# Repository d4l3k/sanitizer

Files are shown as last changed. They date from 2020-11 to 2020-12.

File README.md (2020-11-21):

# sanitizer

Building a box lined with aluminum foil and mounting this in the top of the box
is probably the best way to disinfect things quickly.

## UVC Leds Power by distance away

For a half sphere falloff:

 * $36 mW  /(4 pi * (32 cm)^2/2) * 15*60 seconds = 5 mJ/cm^2$
 * $36 mW  /(4 pi * (100 cm)^2/2) * 2.5*60*60 seconds = 5.157mJ/cm^2$
 * $36 mW  /(4 pi * (200 cm)^2/2) * 10*60*60 seconds = 5.157mJ/cm^2$

## Power to kill SARS-CoV-2

 | power |1.25 mJ/cm^2 |2.5 mJ/cm^2 |3.75 mJ/cm^2 | 5 mJ/cm2 |
 |---|----|---|---|---|
 | time at 1.25 mW/cm^2 |1 second | 2 seconds | 3 seconds | 4 seconds |
 |  260 nm |   |   |   | 2.6 |
 |  268 nm |0.7 | 1.2 | 1.5 | 2.8|
 |  270 nm |   |   |   | 2.8 |

 from https://www.klaran.com/crystal-is-and-boston-university-research-demonstrate-klaran-uvc-leds-effective-wavelength-for-inactivating-sars-cov-2

## Aluminum foil reflectivity

Aluminum foil has a reflectivity of 73% for UVC light.

https://www.klaran.com/images/kb/application-notes/Using-UV-Reflective-Materials-to-Maximize-Disinfection---Application-Note---AN011.pdf

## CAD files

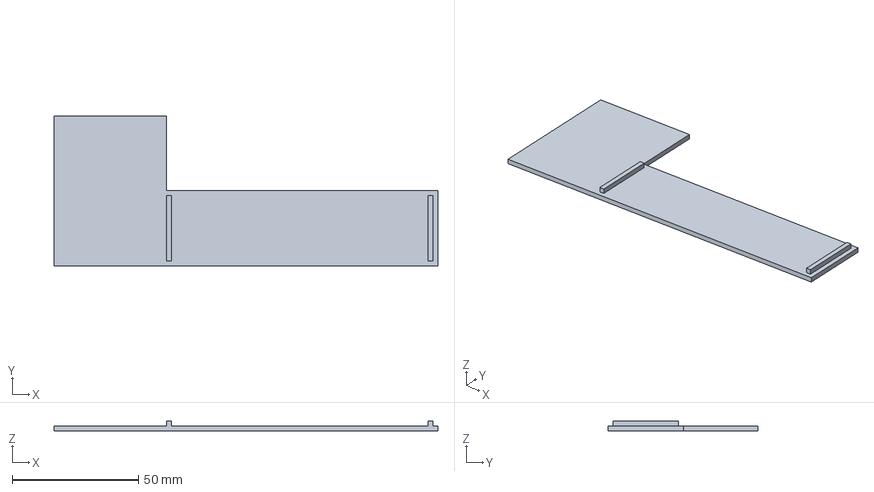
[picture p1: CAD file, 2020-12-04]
sanitizer-case-top.amf
152.2 x 59.6 x 4.00 mm

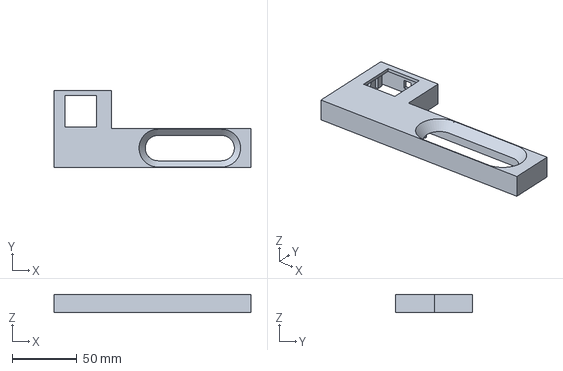
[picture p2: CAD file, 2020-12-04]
sanitizer-case.amf
152.2 x 59.6 x 14.0 mm

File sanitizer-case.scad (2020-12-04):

$fn = 50;

board_width = 25;
  board_length = 110;
  board_hole_size = 1.5;
  board_max_height = 6.15;
  board_min_height = 1.44;
 
board_hole1_offset = 79.5;
board_hole2_offset = 5.5;
  
module led_board() {
  
  led_size = 3.58;
  
  translate([0, -board_width/2])
  difference() {
    union() {
    cube([board_length, board_width, board_min_height]);
    cube([board_width, board_width, board_max_height]);
    }
    
      
    translate([board_length-board_hole1_offset-board_hole_size, board_width/2, -1])
    cylinder(r=board_hole_size, h=5);
    
    translate([board_length-board_hole2_offset-board_hole_size, board_width/2, -1])
    cylinder(r=board_hole_size, h=5);

  }
  
  for (d = [76.95, 46.97, 16.62]) {
    translate([board_length-d, -led_size/2, board_min_height])
    cube([led_size, led_size, 1.6]);
  }
}

 strip_width = 10.1;
  strip_length = 33;
  led_size = 5;

module led_strip() {
  translate([0, -strip_width/2])
  union() {
    cube([strip_length, strip_width, 0.26]);
    
    translate([strip_length/2-led_size/2,strip_width/2-led_size/2])
    cube([led_size, led_size, 2]);
  }
}
  thread_outer = 6.8;
  thread_inner = 6.13;
  thread_length = 6.23;
  lip_outer = 9.5;
  lip_length = 2;
  barrel_diameter = 7.37;
  barrel_length = 12.5;
  stem_diameter=4.5;
  stem_length = 2.2;
  button_diameter=6;
  button_length = 3.7;

module button() {
  translate([0, 0, -barrel_length-lip_length]) {
  cylinder(d=barrel_diameter, h=barrel_length);
  translate([0,0,barrel_length])
  cylinder(d=lip_outer, h=lip_length);
  translate([0,0,barrel_length+lip_length])
  cylinder(d=thread_outer, h=thread_length);
  translate([0,0,barrel_length+lip_length+thread_length])
  cylinder(d=stem_diameter, h=stem_length);
    translate([0,0,barrel_length+lip_length+thread_length+stem_length])
  cylinder(d=button_diameter, h=button_length);
  }

}

  sensor_length = 32.57;
  sensor_width = 24.26;
  sensor_height = 11;
  cap_size = 23.25;
  cap_base = 3.4;
  
module motion_sensor() {

  translate([0, -sensor_width/2])
    
  union() {
    cube([sensor_length, sensor_width, sensor_height]);
    
    translate([sensor_length/2-cap_size/2, sensor_width/2-cap_size/2, sensor_height])
    union() {
    cube([cap_size, cap_size, cap_base]);
      translate([cap_size/2, cap_size/2, cap_base])
      sphere(cap_size/2);
    }
  }
}
chip_hole_radius = 2.9/2;

module chip_hole() {
  cylinder(r=chip_hole_radius, h=5);
}

chip_width = 25.63;
chip_length = 48.42;
chip_height = 1.63;
port_width = 11.5;
port_height = 6.78;
port_length = 24.40;

pin_width = 2.57;
pin_length = 36.16;
pin_height = 8.31;

chip_hole_offset_x = 0.8;
chip_hole_offset_y = 1.06;


module chip() {
  
  translate([0, -chip_width/2])
  union() {
  
  translate([0, chip_width/2+(port_width-port_height)/2, 6.14-port_height])
  rotate([90, 0, 270])
  union() {
    cube([port_width-port_height, port_height, port_length]);
    translate([0, port_height/2])
    union() {
      cylinder(d=port_height, h=port_length);

      translate([port_width-port_height, 0])
      cylinder(d=port_height, h=port_length);
    }
  }
  
  difference() {
    cube([chip_length, chip_width, chip_height]);
    
    translate([chip_hole_radius+chip_hole_offset_x, chip_hole_radius+chip_hole_offset_y,-1])
    chip_hole();
    translate([chip_hole_radius+chip_hole_offset_x, chip_width-chip_hole_offset_y-chip_hole_radius,-1])
    chip_hole();
    
    translate([chip_length-chip_hole_radius-chip_hole_offset_x, chip_hole_radius+chip_hole_offset_y,-1])
    chip_hole();
    translate([chip_length-chip_hole_radius-chip_hole_offset_x, chip_width-chip_hole_offset_y-chip_hole_radius,-1])
    chip_hole();
  }

  
  translate([chip_length/2-pin_length/2, 0, -pin_height])
  union() {
    cube([pin_length, pin_width, pin_height]);
    translate([0, chip_width-pin_width])
      cube([pin_length, pin_width, pin_height]);
  }
  }
}
  small_chip_width = 25.8;
  small_chip_length = 34.21;
  small_chip_height = 4.28; // includes boards
  small_board_height = 1.16;




module small_chip() {
  board_width = small_chip_width;
    board_length = small_chip_length;
  board_height = small_board_height;

  cube([board_length, board_width, board_height]);
  
  subboard_width = 16;
  subboard_length = 24.16;
  translate([board_length-subboard_length, (board_width-subboard_width)/2, board_height])
  cube([24.16, 16, 0.8]);
  
  chip_width = 11.88;
  chip_length = 15;
  
  translate([11.55, (board_width-chip_width)/2, 0])
  cube([chip_length, chip_width, small_chip_height]);
  
  translate([0, board_width/2+(port_width-port_height)/2, 0.84-port_height+board_height])
  rotate([90, 0, 270])
  union() {
    cube([port_width-port_height, port_height, port_length]);
    translate([0, port_height/2])
    union() {
      cylinder(d=port_height, h=port_length);

      translate([port_width-port_height, 0])
      cylinder(d=port_height, h=port_length);
    }
  }
}

e = 0.5;
case_height = sensor_height + e * 2;
shell = 2;
long_width = board_width + e*2;
long_length = board_length + small_chip_length + e*4 + shell;
box_width = small_chip_width + e*5 + sensor_width + shell* 1.5;
box_length = 40+e;
height = case_height;

led_board_offset = small_chip_length+shell + e*3;
row2 = small_chip_width + sensor_width/2 + shell + e*3;

module components() {
 translate([e, e, -small_chip_height-e])
small_chip();

translate([led_board_offset, long_width/2, -board_max_height-e])
led_board();

translate([shell+e, row2, -sensor_height-e])
motion_sensor();

translate([0, row2, -case_height/2])
rotate([90, 0, -90])
button();

translate([box_length/2-strip_length/2, box_width, -height/2])
  rotate([-90, 0, 0])
led_strip();
}


tab = 4;

module part() {

translate([0, 0, -height]) {
  difference () {
    union() {

  
  translate([small_chip_length+e*2, small_chip_width-tab+e])
  cube([shell, tab+shell, height]);
  translate([small_chip_length+e*2-tab, small_chip_width+e*2])
  cube([tab+shell, shell, height]);
  translate([0, small_chip_width+e*2])
  cube([tab, shell, height]);
  
  translate([0, small_chip_width+e*2])
  cube([shell, tab+shell, height]);
  
  translate([0, box_width-tab-shell])
  cube([shell, tab, height]);
  
  translate([sensor_length+e*2+shell, small_chip_width+e*2])
  cube([shell, tab+shell, height]);
  
  translate([sensor_length+e*2+shell, box_width-tab-shell])
  cube([shell, tab, height]);
  
  lip_height = small_chip_height-small_board_height;
  translate([0, 0, height-lip_height])
  cube([lip_height, small_chip_width, lip_height]);
  
  board_filler_height = board_max_height-board_min_height-e;
  translate([led_board_offset+board_width+e, 0, height-board_filler_height])
  cube([board_length-board_width, long_width, board_filler_height]);
  
  translate([led_board_offset+board_length-board_hole_size, board_width/2+e]) {
      for (offset = [board_hole1_offset, board_hole2_offset]) {
        translate([-offset, 0, height-board_max_height-e])
        cylinder(r=(board_hole_size-e/2), h=board_max_height+e);
      }
    }

  difference () {
    union() {
      translate([-shell, -shell, 0]) {
        cube([long_length+shell*2, long_width+shell*2, height+shell]);
        cube([box_length+shell*2, box_width+shell*2, height+shell]);
      }

      
    }


    translate([0,0, -shell]) {
      cube([long_length, long_width, height+shell]);
      cube([box_length, box_width, height+shell]);
    }

    hole_height = 2.35;
    translate([-shell*1.5, (small_chip_width-port_width*1.1)/2+e, hole_height])
    cube([shell*2, port_width*1.1, port_height*1.1]);


    led_hole_size = led_size+e;

    translate([(box_length-led_hole_size)/2, box_width-shell*0.5, (height-led_hole_size)/2])
    cube([led_hole_size, shell*2, led_hole_size]);
    
    // button hole
    translate([e, row2, case_height/2])
    rotate([90, 0, -90])
    cylinder(d=thread_outer+2*e, h=shell*2);
    
    // sensor hole
    translate([(sensor_length-cap_size)/2+shell, row2-cap_size/2-e, height-shell/2])
    cube([cap_size+2*e, cap_size+2*e, shell*2]);
  }
}

    
    // LED hole
    led_hole_height = board_max_height-board_min_height+shell+e;
    hole_top = long_width+shell*2;
    hole_bottom = board_width*3/4;
    hole_length = board_hole1_offset-board_hole2_offset-board_hole_size*4-hole_bottom;
    
    translate([led_board_offset +hole_bottom/2+board_length-board_hole1_offset+board_hole_size*0.5,long_width-hole_top+shell,height+shell-led_hole_height+e]) {
      
      translate([0, hole_top/2, 0])
      cylinder(d1=hole_bottom, d2=hole_top, h=led_hole_height);
      
      translate([hole_length, hole_top/2, 0])
      cylinder(d1=hole_bottom, d2=hole_top, h=led_hole_height);

    
      translate([0, hole_top, led_hole_height])
      rotate([90, 180, 90])
      linear_extrude(height=hole_length, $fn=1)
      polygon(points=[
        [0, 0], [hole_top, 0], 
        [hole_top-(hole_top-hole_bottom)/2,led_hole_height],
        [(hole_top-hole_bottom)/2,led_hole_height],
      ]);    
    }

}
}
}
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

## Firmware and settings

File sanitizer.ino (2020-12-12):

#include <ESP8266WiFi.h>
#include <WiFiClient.h>
#include <ESP8266WiFiMulti.h> 
#include <ESP8266mDNS.h>
#include <ESP8266WebServer.h>
#include <FastLED.h>

#define ACTIVATION_DELAY 10*1000
#define UVC_DURATION 15*60*1000
#define BUTTON_DEBOUNCE_DUR 100

#define LED_PIN 2 //Define blinking LED pin
#define UVC_PIN 14
#define BUTTON_PIN 0
#define RGB_LED_PIN 4
#define NUM_LEDS 1
#define MOTION_SENSOR_PIN 5

ESP8266WiFiMulti wifiMulti;     // Create an instance of the ESP8266WiFiMulti class, called 'wifiMulti'
ESP8266WebServer server(80);    // Create a webserver object that listens for HTTP request on port 80

#include "./networks.h"

CRGB leds[NUM_LEDS];

int buttonDownTime = 0;
bool lastButton = false;
boolean connectionWasAlive = true;

int timeInUVC = 0;
int stateEntered = 0;
enum states{READY, ACTIVATING, UVC};
enum states state = READY;

void setup() {
  pinMode(LED_PIN, OUTPUT);
  pinMode(UVC_PIN, OUTPUT);
  pinMode(MOTION_SENSOR_PIN, INPUT);
  pinMode(BUTTON_PIN, INPUT_PULLUP);

  Serial.begin(115200);

  setupNetworks();

  FastLED.addLeds<WS2812, RGB_LED_PIN, GRB>(leds, NUM_LEDS);

  server.on("/activate", HTTP_POST, postActivate);
  server.on("/", HTTP_GET, getDebug);

  setState(READY);
}

void postActivate() {
  if (state == READY) {
    setState(ACTIVATING);
    server.send(200, "text/html", "activating!");
  } else {
    server.send(500, "text/html", "can't activate, state="+String(state));
  }
}

void getDebug() {
  server.send(200, "application/json", 
  "{\"state\": "+String(state)+", \"state_entered\": "+String(millis() - stateEntered)+"}");
}

int lastLogged = 0;

void monitorWiFi() {
  if (wifiMulti.run() != WL_CONNECTED){
    if (connectionWasAlive) {
      connectionWasAlive = false;
      Serial.print("Looking for WiFi ");
    }
    int now = millis();
    if ((now - lastLogged) > 1000) {
      Serial.print(".");
      lastLogged = now;
    }
  } else {
    if (!connectionWasAlive) {
      connectionWasAlive = true;
      Serial.printf(" connected to %s\n", WiFi.SSID().c_str());
  
      server.begin();
      if (MDNS.begin("sanitizer")) {
        Serial.println("mDNS responder started");
      } else {
        Serial.println("Error setting up MDNS responder!");
      }
    }
    
    server.handleClient(); 
  }
}

void setState(enum states newState) {
  if (newState == state) {
    return;
  }
  if (state == UVC) {
    timeInUVC += timeInState();
  }
  if (newState == READY) {
    timeInUVC = 0;
  }
  Serial.printf("entering state %d\r\n", newState);
  state = newState;
  resetStateEntered();
}

void resetStateEntered() {
  stateEntered = millis();
}

int timeInState() {
  return millis() - stateEntered;
}

void updateLEDs(bool motion) {
  CRGB color;
  bool flashing = false;
  
  if (state == READY) {
    color = CRGB ( 0, 0, 255);
  } else if (state == UVC) {
    color = CRGB ( 255, 0, 0);
    flashing = true;
  } else if (state == ACTIVATING) {
    color = CRGB ( 255,150, 0);
    flashing = true;
  }
  
  if (motion && (state == READY || state == ACTIVATING)) {
    color = CRGB ( 0, 255, 0);
  } 

  FastLED.setBrightness(flashing ? 255 : 100);

  if (flashing && ((millis() / 250) % 2 == 0)) {
    color = CRGB(0,0,0);
  }
  for (int i = 0; i<NUM_LEDS; i++) {
    leds[i] = color;
  }
  
  FastLED.show();
}

// the loop function runs over and over again forever
void loop() {
  bool motion = digitalRead(MOTION_SENSOR_PIN) == HIGH;
  if (motion) {
    digitalWrite(LED_PIN, LOW); // Turn the LED on (Note that LOW is the voltage level)
  } else {
    digitalWrite(LED_PIN, HIGH); // Turn the LED off by making the voltage HIGH
  }

  if (state == UVC) {
    digitalWrite(UVC_PIN, HIGH); // turn UVC on
  } else {
    digitalWrite(UVC_PIN, LOW); // turn UVC off
  }
  bool curButton = digitalRead(BUTTON_PIN) == LOW && timeInState() >= 1000;
  // button edge trigger on release
  bool buttonPress = curButton && !lastButton;
  if (buttonPress) {
    buttonDownTime = millis();
  }
  bool button = !curButton && lastButton && (millis() - buttonDownTime) > BUTTON_DEBOUNCE_DUR;
  lastButton = curButton;

  if ((state == UVC || state == ACTIVATING) && button) {
    setState(READY);
  } else if (state == UVC && motion) {
    setState(ACTIVATING);
  } else if (state == ACTIVATING && motion) {
    resetStateEntered();
  } else if (state == READY && button) {
    setState(ACTIVATING);
  } else if (state == ACTIVATING && timeInState() > ACTIVATION_DELAY) {
    setState(UVC);
  } else if (state == UVC && timeInUVC > UVC_DURATION) {
    setState(READY);
  } 

  updateLEDs(motion);
  monitorWiFi();
}

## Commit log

2020-11-19 made debug info more useful + made button triggering less buggy
    [sanitizer.ino]
2020-11-20 beginnings of sanitizer case
    [sanitizer-case.scad]
2020-11-21 added notes on power levels
2020-12-02 updated sanitizer case top
    [sanitizer-case.amf, sanitizer-case.scad]
2020-12-02 tweaked proportions after test print
    [sanitizer-case.scad]
2020-12-04 added case top
    [sanitizer-case-top.amf, sanitizer-case.amf, sanitizer-case.scad]
2020-12-12 reworked logic so motion doesn't cancel, just pauses
    [sanitizer.ino]
